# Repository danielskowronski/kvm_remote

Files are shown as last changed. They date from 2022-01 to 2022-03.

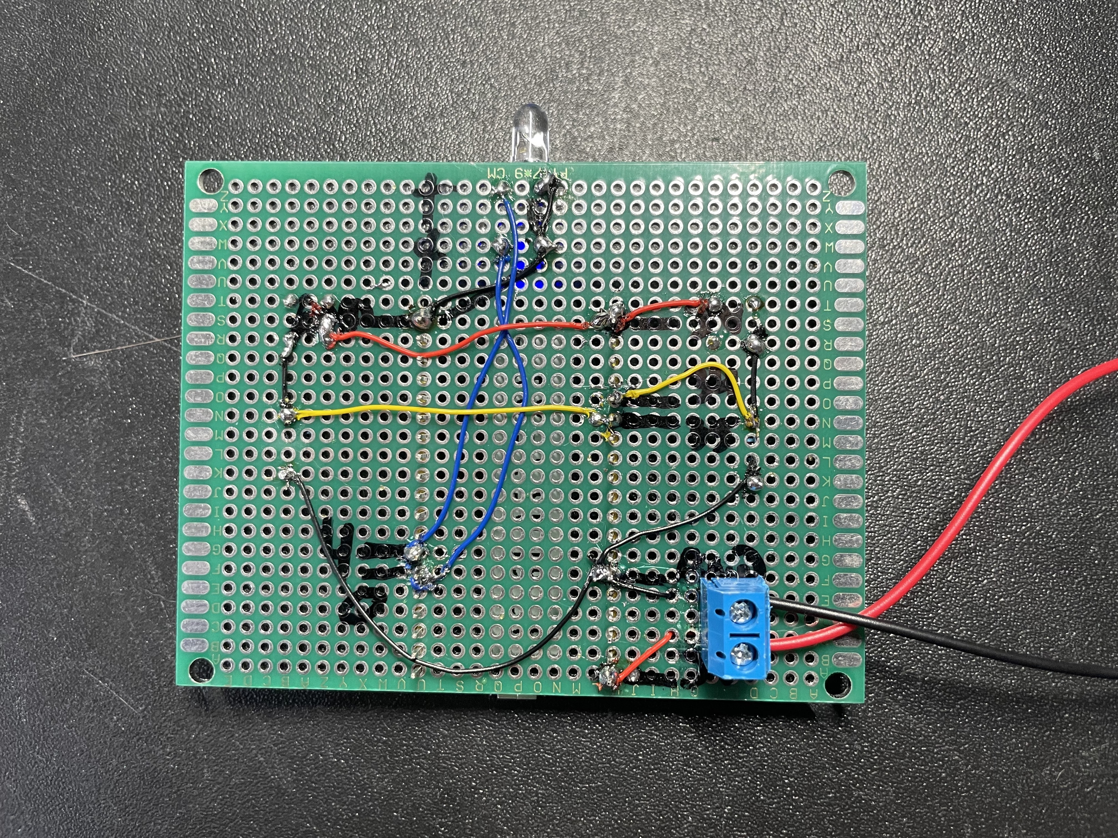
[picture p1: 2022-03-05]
board/demo/back.jpeg

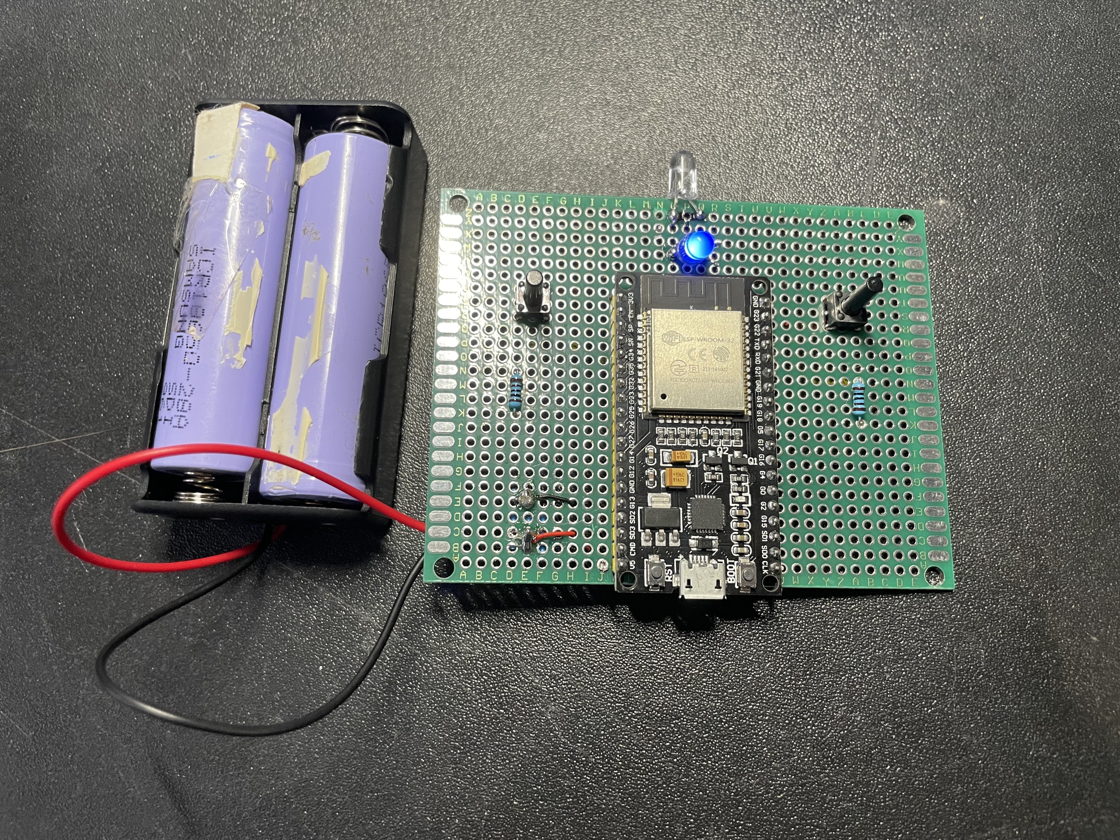
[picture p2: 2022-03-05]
board/demo/front.jpeg

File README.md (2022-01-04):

# kvm_remote

Makeshift remote controller for my KVM setup - seperate HDMI matrix switcher and USB switcher - both IR controlled.

Based on ESP32 with Arduino, target version on wired prototype PCB in 3D printed case.

## Controlled hardware

* Caneov 4X2 Hdmi2.0 Matrix Switch Splitter 4K60Hz Switcher (HDMX402)
* AIMOS AM-404CY KVM 4 port

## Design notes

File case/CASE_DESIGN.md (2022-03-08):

# Case Design

## elements

### plan

4 edges in top half:
- screw
- (top cover)
- distance bolt
- (prototype board)
- distance bolt
- (board-batteries wall)
- nut

4 edges in bottom half:
- nut
- (10 mm high hex slot)
- distance bolt
- (bottom cover)
- screw

2 holes in battery holder:
- nut
- (battery holder)
- screw

### BOM

- M3 screws (x10):
  - 4 for top cover
  - 2 for battery holder
  - 4 for bottom cover
- M3 distance bolt 10 mm (x12):
  - 4 for attaching top cover to prototype board
  - 4 for attaching prototype board to board-batteries wall (screwed to other 4)
  - 4 for attaching bottom cover to case
- M3 nut (x10):
  - 4 for attaching prototype board's distance bolts to board-batteries wall
  - 2 for battery holder
  - 4 for attaching bottom cover's distance bolts to board-batteries wall

## Layout

### from sides

- 02.0 mm removable top 
- 10.0 mm for board components, topmost: microUSB
- 01.5 mm prototype board itself
- 10.0 mm for board pins (min is 5 mm, but standard coupling nut is 10 mm)
- 02.0 mm board-batteries wall with slot for power screw terminals
- 21.0 mm 2x 18650 battery holder
- 02.0 mm safe space
- 02.0 mm removable bottom

total height: 46.5 mm

### from top

board is 70x90 mm, extra space from each side will be 5 mm => 100x80 mm

## Parts

### Top & bottom

generally the same base, but top with 3 additional holes (LED and buttons) and extruded labels

something like https://www.openscad.info/index.php/2020/07/07/the-easiest-project-box/ without screw posts, but with holes instead

```scad
$fn=25;
BOX_W = 80;
BOX_L = 100;
BOX_H = 10;
CORNER_RADIUS = 3; // Radius of corners
WALL_THICKNESS = 2;// Wall Thickness

linear_extrude( BOX_H )
    difference(){
        offset(r=CORNER_RADIUS) 
            square( [BOX_W, BOX_L], center=true );
        
        offset( r= CORNER_RADIUS - WALL_THICKNESS )
            square( [BOX_W-WALL_THICKNESS, BOX_L-WALL_THICKNESS], center=true );
    }

coordinates = [ [0,0],[0,BOX_L],[BOX_W,BOX_L],[BOX_W,0] ];

translate ( [-BOX_W/2, -BOX_L/2] )
    hull()
    for (i = coordinates)
        translate(i) sphere(CORNER_RADIUS);

// TODO: screw holes
```

M3 (3.1 major dia) screw holes' centers positioned:
- 10 mm from shorter edges (wall 2, disatnce to board 5, from board edge 2)
- 9 mm  from  longer edges (wall 2, disatnce to board 5, from board edge 3)

### main body

based on above code two conjoined elements

```
|                 |
|                 |
--  ---------------
||               ||
||               ||
```

top half:    11.5 mm
wall:         2.0 mm
bottom half: 15.0 mm

wall have hole for battery connector positioned:
- from left 2 mm (side thickness) to 28 mm (wall 2, disatnce to board 5, element reaches 21 into board)
- from bottom 2 mm (side thickness) to 23 mm(wall 2, disatnce to board 5, element reaches 16 into board)

bottom half have additional hex spaces for distancing rods positioned so the center of hole will be in the same place as covers' holes:
- hex dia of rod is 4.6 mm

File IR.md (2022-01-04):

# IR signals

## Program
```c++
#include <Arduino.h>
#include <IRremote.hpp>

int IR_RECEIVE_PIN = 15;

void setup() {
  Serial.begin(115200);
  IrReceiver.begin(IR_RECEIVE_PIN, false); 
  Serial.println("IR Receiver ready");
}

void loop() {
  if (IrReceiver.decode()) {
      IrReceiver.printIRResultShort(&Serial);
      IrReceiver.resume();
  }
  delay(100);
}
```

## USB: AIMOS AM-404CY KVM 4 port
```
PC1 Protocol=NEC Address=0x1  Command=0x3  Raw-Data=0xFC03FE01 32 bits LSB first
PC2 Protocol=NEC Address=0x1  Command=0x0  Raw-Data=0xFF00FE01 32 bits LSB first
PC3 Protocol=NEC Address=0x1  Command=0x7  Raw-Data=0xF807FE01 32 bits LSB first
PC4 Protocol=NEC Address=0x1  Command=0x4  Raw-Data=0xFB04FE01 32 bits LSB first
TGL Protocol=NEC Address=0x1  Command=0x1F Raw-Data=0xE01FFE01 32 bits LSB first
```

## HDMI: Caneov 4X2 Hdmi2.0 Matrix Switch Splitter 4K60Hz Switcher (HDMX402)
```
A_1 Protocol=NEC Address=0x80 Command=0x1  Raw-Data=0xFE017F80 32 bits LSB first
A_2 Protocol=NEC Address=0x80 Command=0x2  Raw-Data=0xFD027F80 32 bits LSB first
A_3 Protocol=NEC Address=0x80 Command=0x3  Raw-Data=0xFC037F80 32 bits LSB first
A_4 Protocol=NEC Address=0x80 Command=0x6  Raw-Data=0xF9067F80 32 bits LSB first

A_L Protocol=NEC Address=0x80 Command=0x4  Raw-Data=0xFB047F80 32 bits LSB first
A_R Protocol=NEC Address=0x80 Command=0x5  Raw-Data=0xFA057F80 32 bits LSB first

B_1 Protocol=NEC Address=0x80 Command=0xA  Raw-Data=0xF50A7F80 32 bits LSB first
B_2 Protocol=NEC Address=0x80 Command=0x1B Raw-Data=0xE41B7F80 32 bits LSB first
B_3 Protocol=NEC Address=0x80 Command=0x1F Raw-Data=0xE01F7F80 32 bits LSB first
B_4 Protocol=NEC Address=0x80 Command=0xE  Raw-Data=0xF10E7F80 32 bits LSB first

B_L Protocol=NEC Address=0x80 Command=0xC  Raw-Data=0xF30C7F80 32 bits LSB first
B_R Protocol=NEC Address=0x80 Command=0xD  Raw-Data=0xF20D7F80 32 bits LSB first

PWR Protocol=NEC Address=0x80 Command=0x12 Raw-Data=0xED127F80 32 bits LSB first
ARC Protocol=NEC Address=0x80 Command=0x1E Raw-Data=0xE11E7F80 32 bits LSB first
```

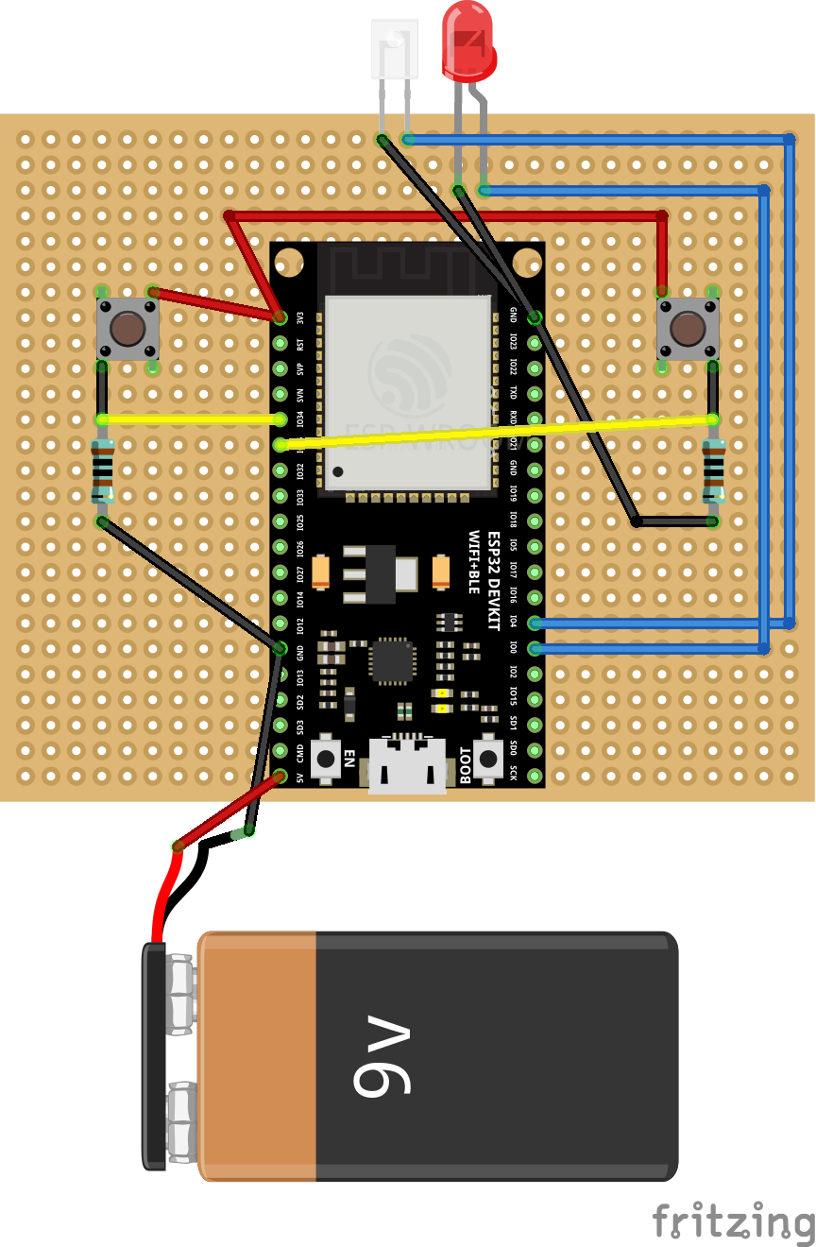
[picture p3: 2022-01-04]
board/kvm_remote_bb.png

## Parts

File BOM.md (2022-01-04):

# Bill of Materials (BOM)

* ESP32 dev board - `ESP-WROOM-32` in 38-pin variant
* 1x IR emmiting diode
* 2x momentary switch
* 2x 1k resistor 
* 9V battery holder
* empty prototyope board with 2.54mm pitch, here used 31x26 holes
* optional: 1x IR receiver for research/learning phase

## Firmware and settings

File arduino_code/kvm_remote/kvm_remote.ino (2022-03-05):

#include <Arduino.h>
#include <IRremote.h>

// GPIO ports
#define IR_SEND 4
#define BUTTON_PC1 34
#define BUTTON_PC2 35
#define BUTTON_PIN_BITMASK 0xc00000000 // GPIO 34 and GPIO 35

// IR codes: AIMOS AM-404CY KVM 4 port
#define USB__ADR 0x1
#define USB__PC1 0x3 
#define USB__PC2 0x0 
#define USB__PC3 0x7 
#define USB__PC4 0x4 
#define USB__TGL 0x1F

// IR codes: Caneov 4X2 Hdmi2.0 Matrix Switch Splitter 4K60Hz Switcher (HDMX402)
#define HDMI_ADR 0x80
#define HDMI_A_1 0x1  
#define HDMI_A_2 0x2  
#define HDMI_A_3 0x3  
#define HDMI_A_4 0x6  
#define HDMI_A_L 0x4  
#define HDMI_A_R 0x5  
#define HDMI_B_1 0xA  
#define HDMI_B_2 0x1B 
#define HDMI_B_3 0x1F 
#define HDMI_B_4 0xE  
#define HDMI_B_L 0xC  
#define HDMI_B_R 0xD  
#define HDMI_PWR 0x12 
#define HDMI_ARC 0x1E 

void setup() {
  Serial.begin(115200);
  IrSender.begin(); // this library on ESP32 ignores every form of providing send pin and uses GPIO4

  uint64_t GPIO_reason = esp_sleep_get_ext1_wakeup_status();
  Serial.print("GPIO that triggered the wake up: GPIO ");
  int reason = (log(GPIO_reason))/log(2);
  Serial.println(reason, 0);
  
  delay(500);

  if (reason==34) setPC1();
  else if (reason==35) setPC2();
  
  esp_sleep_enable_ext1_wakeup(BUTTON_PIN_BITMASK,ESP_EXT1_WAKEUP_ANY_HIGH);
  //esp_sleep_pd_config(ESP_PD_DOMAIN_RTC_PERIPH, ESP_PD_OPTION_ON);

  pinMode(0, OUTPUT); 
  digitalWrite(0, LOW);

  esp_deep_sleep_start();
}

void setPC1(){
  Serial.printf("PC1 (priv): USB2, HDMI3+4\n");
  delay(100);  
  IrSender.sendNEC(USB__ADR, USB__PC2, 0, false);
  delay(100);
  IrSender.sendNEC(HDMI_ADR, HDMI_A_3, 3, false);
  delay(250);
  IrSender.sendNEC(HDMI_ADR, HDMI_B_4, 3, false);
}
void setPC2(){
  Serial.printf("PC2 (corp): USB4, HDMI1+2\n");
  delay(100);  
  IrSender.sendNEC(USB__ADR, USB__PC4, 0, false);
  delay(100);
  IrSender.sendNEC(HDMI_ADR, HDMI_A_1, 3, false);
  delay(250);
  IrSender.sendNEC(HDMI_ADR, HDMI_B_2, 3, false);
}

void loop() {
  Serial.println("never reached");
  delay(1000);
}

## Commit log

2021-12-31 initial version of board layout for blank pcb - excel
    [layout.xlsx]
2021-12-31 initial version of IR transmitter code with ESP32 deep sleep
2022-01-04 transfer board layout to fritzing
    [kvm_remote.fzz]
2022-03-05 board demo and initial case design
2022-03-05 code update to correctly send hdmi switch codes as well as use new switches layout
    [kvm_remote.ino]
2022-03-08 case design plan iteration
